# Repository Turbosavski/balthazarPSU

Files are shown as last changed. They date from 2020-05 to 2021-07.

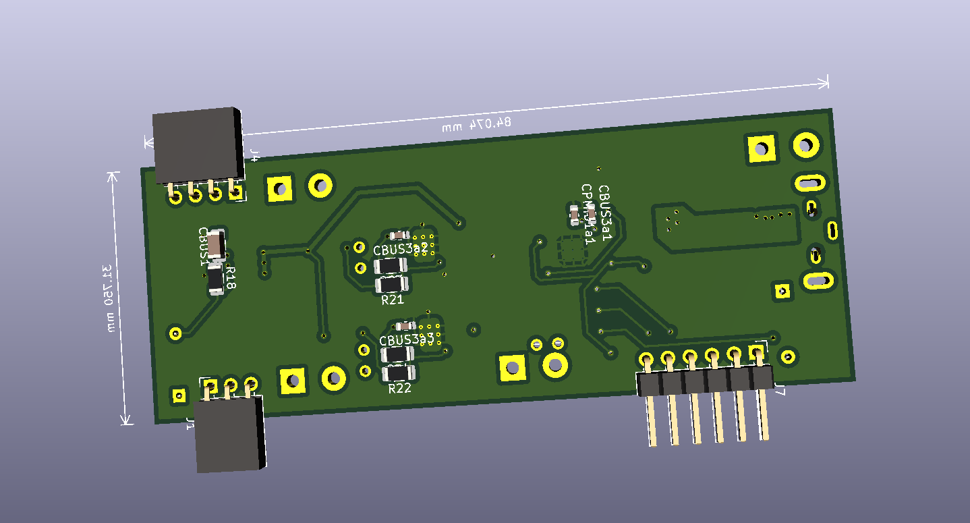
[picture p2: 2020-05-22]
BathazarPSU_11.png

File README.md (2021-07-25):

# balthazar
open-hardware laptop computer modules

These are electronic schematic modules as presented at https://balthazar.space/wiki/Balthazar
with the main aim for team access

KiCad 5.1.5 files

# BalthazarPSU 

module BalthazarPSU is a combined 1S battery charger, double buck-boost converter, stereo power amplifier and usb2.0 hub.

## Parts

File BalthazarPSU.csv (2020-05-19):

Reference | Value | Footprint | Datasheet
L1 | 2.2uH 4A | Inductor_SMD:L_Coilcraft_XxL4020
R7 | 265 | Resistor_SMD:R_1206_3216Metric
R4 | 2K2 | Resistor_SMD:R_1206_3216Metric
R5 | 2K2 | Resistor_SMD:R_1206_3216Metric
D1 | Led | LED_SMD:LED_1206_3216Metric
D2 | Led | LED_SMD:LED_1206_3216Metric
R3 | 10K | Resistor_SMD:R_1206_3216Metric
R2 | 10K | Resistor_SMD:R_1206_3216Metric
R1 | 10K | Resistor_SMD:R_1206_3216Metric
CPMID1 | 10uF | Capacitor_SMD:C_1206_3216Metric
CBUS3 | 1uF | Capacitor_SMD:C_1206_3216Metric
CSYS1 | 10uF | Capacitor_SMD:C_1206_3216Metric
CSYS2 | 10uF | Capacitor_SMD:C_1206_3216Metric
CREGN1 | 1uF | Capacitor_SMD:C_1206_3216Metric
RBTST1 | R | Resistor_SMD:R_1206_3216Metric
CBTST1 | 1uF | Capacitor_SMD:C_1206_3216Metric
R8 | 2K2 | Resistor_SMD:R_1206_3216Metric
R10 | 6K8 | Resistor_SMD:R_1206_3216Metric
THERMISTOR(103-AT)1 | 10K | Resistor_SMD:R_1206_3216Metric
R6 | 10K | Resistor_SMD:R_1206_3216Metric
U1 | PAM8403-SOP16 | Package_SO:SOP-16_4.4x10.4mm_P1.27mm | https://www.diodes.com/assets/Datasheets/PAM8403.pdf
CBUS5 | 1uF | Capacitor_SMD:C_1206_3216Metric
CBUS8 | 1uF | Capacitor_SMD:C_1206_3216Metric
R11 | 2K2 | Resistor_SMD:R_1206_3216Metric
R9 | 2K2 | Resistor_SMD:R_1206_3216Metric
CBUS7 | 0.1uF | Capacitor_SMD:C_1206_3216Metric
CBUS1 | 1uF | Capacitor_SMD:C_1206_3216Metric
CBUS2 | 1uF | Capacitor_SMD:C_1206_3216Metric
CBUS4 | 1uF | Capacitor_SMD:C_1206_3216Metric
D3 | RBR5LAM40A | Diode_SMD:D_SOD-128 | ~
CBAT1 | 10uF | Capacitor_SMD:C_1206_3216Metric
FBEAD3 | 10E | Inductor_SMD:L_Neosid_MicroCoil_Ms36-L
U2 | TPS63020 | Package_SON:WSON-14-1EP_4.0x4.0mm_P0.5mm_EP2.6x2.6mmThermalPads | http://www.ti.com/lit/ds/symlink/tps63060.pdf
U3 | TPS63020 | Package_SON:WSON-14-1EP_4.0x4.0mm_P0.5mm_EP2.6x2.6mmThermalPads | http://www.ti.com/lit/ds/symlink/tps63060.pdf
L2 | 1.5uH 4A | Inductor_SMD:L_Coilcraft_XxL4020
L3 | 1.5uH 4A | Inductor_SMD:L_Coilcraft_XxL4020
C1 | 0.1uF | Capacitor_SMD:C_1206_3216Metric
C2 | 0.1uF | Capacitor_SMD:C_1206_3216Metric
R12 | 1M | Resistor_SMD:R_1206_3216Metric
R14 | 1M | Resistor_SMD:R_1206_3216Metric
R13 | 180K | Resistor_SMD:R_1206_3216Metric
R15 | 180K | Resistor_SMD:R_1206_3216Metric
C3 | 22uF | Capacitor_SMD:C_1206_3216Metric
C5 | 22uF | Capacitor_SMD:C_1206_3216Metric
C7 | 22uF | Capacitor_SMD:C_1206_3216Metric
C9 | 22uF | Capacitor_SMD:C_1206_3216Metric
C4 | 22uF | Capacitor_SMD:C_1206_3216Metric
C6 | 22uF | Capacitor_SMD:C_1206_3216Metric
C8 | 22uF | Capacitor_SMD:C_1206_3216Metric
C10 | 22uF | Capacitor_SMD:C_1206_3216Metric
CSYS4 | 10uF | Capacitor_SMD:C_1206_3216Metric
SW2 | SW_SPST | Button_Switch_THT:SW_DIP_SPSTx01_Slide_6.7x4.1mm_W7.62mm_P2.54mm_LowProfile | ~
R16 | 10K | Resistor_SMD:R_1206_3216Metric
J5 | USB_A_female | Connector_USB:USB_A_CNCTech_1001-011-01101_Horizontal-Female | ~
J6 | USB_OTG_female | Connector_USB:USB_Micro-B_Molex-105133-0031 | ~
D6 | RBR5LAM40A | Diode_SMD:D_SOD-128 | ~
CPSU2 | 1uF | Capacitor_SMD:C_1206_3216Metric
R17 | 10K | Resistor_SMD:R_1206_3216Metric
SW3 | SW_SPST | Button_Switch_THT:SW_DIP_SPSTx01_Slide_6.7x4.1mm_W7.62mm_P2.54mm_LowProfile | ~
R18 | 10K | Resistor_SMD:R_1206_3216Metric
FBEAD2 | 10E | Inductor_SMD:L_Neosid_MicroCoil_Ms36-L
PSU1 | 3.9 - 17V adapter 3-5A | TerminalBlock:TerminalBlock_bornier-2_P5.08mm | ~
IC1 | BQ24193 | Package_DFN_QFN:QFN-24-1EP_4x4mm_P0.5mm_EP2.7x2.7mm_ThermalVias
J8 | 3.3V 4A | TerminalBlock:TerminalBlock_bornier-2_P5.08mm | ~
J4 | AudioOUT | Connector_PinSocket_2.54mm:PinSocket_1x04_P2.54mm_Horizontal | ~
J1 | AudioIN | Connector_PinSocket_2.54mm:PinSocket_1x03_P2.54mm_Horizontal | ~
R19 | 0 | Resistor_SMD:R_1206_3216Metric
R20 | 0 | Resistor_SMD:R_1206_3216Metric
J7 | host (promicro) | Connector_PinHeader_2.54mm:PinHeader_1x06_P2.54mm_Horizontal | ~
THERM1 | thermistor | TestPoint:TestPoint_2Pads_Pitch2.54mm_Drill0.8mm | ~
R23 | 1M | Resistor_SMD:R_1206_3216Metric
R24 | 1M | Resistor_SMD:R_1206_3216Metric
R22 | 2K2 | Resistor_SMD:R_1206_3216Metric
D5 | Led | LED_SMD:LED_1206_3216Metric
R21 | 2K2 | Resistor_SMD:R_1206_3216Metric
D4 | Led | LED_SMD:LED_1206_3216Metric
CSYS3 | 10uF | Capacitor_SMD:C_1206_3216Metric
R26 | 270K | Resistor_SMD:R_1206_3216Metric
J11 | 3.3V/5V | TestPoint:TestPoint_2Pads_Pitch2.54mm_Drill0.8mm | ~
J10 | 3.3V/5V | TestPoint:TestPoint_2Pads_Pitch2.54mm_Drill0.8mm | ~
R25 | 270K | Resistor_SMD:R_1206_3216Metric
CPSU1 | 1uF | Capacitor_SMD:C_1206_3216Metric
BATT1 | 1s LiPo | TerminalBlock:TerminalBlock_bornier-2_P5.08mm | ~
CBUS3a1 | 0.1uF | Capacitor_SMD:C_0805_2012Metric
CPMID1a1 | 0.1uF | Capacitor_SMD:C_0805_2012Metric
CBUS3a3 | 0.1uF | Capacitor_SMD:C_0805_2012Metric
CBUS3a2 | 0.1uF | Capacitor_SMD:C_0805_2012Metric
J9 | 3.3V 4A | TerminalBlock:TerminalBlock_bornier-2_P5.08mm | ~

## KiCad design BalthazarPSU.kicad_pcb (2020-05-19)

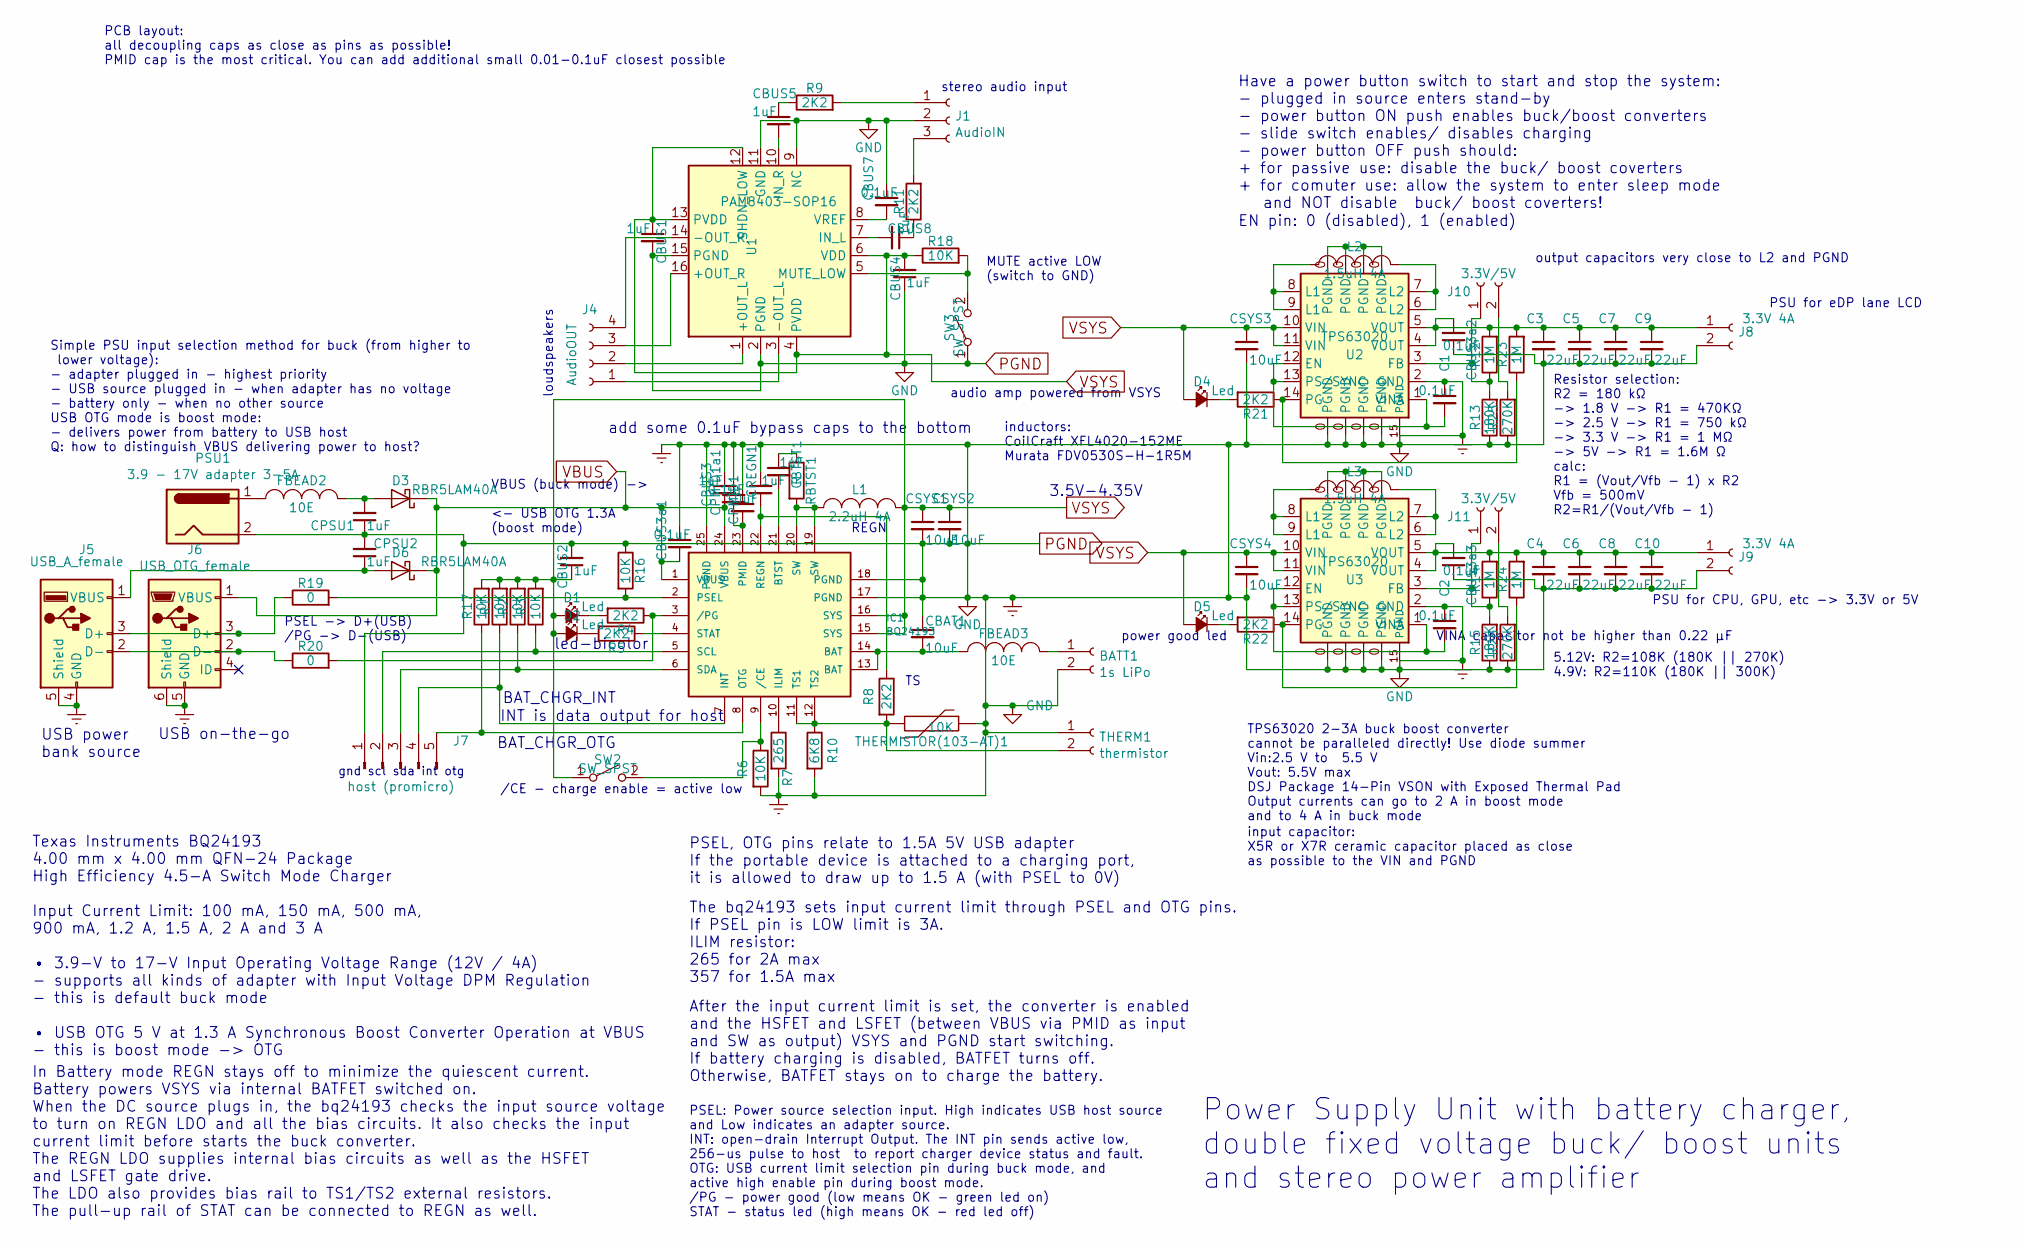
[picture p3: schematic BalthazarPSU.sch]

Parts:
BATT1: 1s LiPo; TerminalBlock_bornier-2_P5.08mm
C1, C2: 0.1uF; C_1206_3216Metric
C3, C4, C5, C6, C7, C8, C9, C10: 22uF; C_1206_3216Metric
CBAT1: 10uF; C_1206_3216Metric
CBTST1: 1uF; C_1206_3216Metric
CBUS1, CBUS2, CBUS3, CBUS4, CBUS5, CBUS8: 1uF; C_1206_3216Metric
CBUS3a1, CBUS3a2, CBUS3a3: 0.1uF; C_0805_2012Metric
CBUS7: 0.1uF; C_1206_3216Metric
CPMID1: 10uF; C_1206_3216Metric
CPMID1a1: 0.1uF; C_0805_2012Metric
CPSU1, CPSU2: 1uF; C_1206_3216Metric
CREGN1: 1uF; C_1206_3216Metric
CSYS1, CSYS2, CSYS3, CSYS4: 10uF; C_1206_3216Metric
D1, D2, D4, D5: Led; LED_1206_3216Metric
D3, D6: RBR5LAM40A; D_SOD-128
FBEAD2, FBEAD3: 10E; L_Neosid_MicroCoil_Ms36-L
IC1: BQ24193; QFN-24-1EP_4x4mm_P0.5mm_EP2.7x2.7mm_ThermalVias
J1: AudioIN; PinSocket_1x03_P2.54mm_Horizontal
J4: AudioOUT; PinSocket_1x04_P2.54mm_Horizontal
J5: USB_A_female; USB_A_CNCTech_1001-011-01101_Horizontal-Female
J6: USB_OTG_female; USB_Micro-B_Molex-105133-0031
J7: host (promicro); PinHeader_1x06_P2.54mm_Horizontal
J8, J9: 3.3V 4A; TerminalBlock_bornier-2_P5.08mm
J10, J11: 3.3V/5V; TestPoint_2Pads_Pitch2.54mm_Drill0.8mm
L1: 2.2uH 4A; L_Coilcraft_XxL4020
L2, L3: 1.5uH 4A; L_Coilcraft_XxL4020
PSU1: 3.9 - 17V adapter 3-5A; TerminalBlock_bornier-2_P5.08mm
R1, R2, R3, R6, R16, R17, R18: 10K; R_1206_3216Metric
R4, R5, R8, R9, R11, R21, R22: 2K2; R_1206_3216Metric
R7: 265; R_1206_3216Metric
R10: 6K8; R_1206_3216Metric
R12, R14, R23, R24: 1M; R_1206_3216Metric
R13, R15: 180K; R_1206_3216Metric
R19, R20: 0; R_1206_3216Metric
R25, R26: 270K; R_1206_3216Metric
RBTST1: R; R_1206_3216Metric
SW2, SW3: SW_SPST; SW_DIP_SPSTx01_Slide_6.7x4.1mm_W7.62mm_P2.54mm_LowProfile
THERM1: thermistor; TestPoint_2Pads_Pitch2.54mm_Drill0.8mm
THERMISTOR(103-AT)1: 10K; R_1206_3216Metric
U1: PAM8403-SOP16; SOP-16_4.4x10.4mm_P1.27mm
U2, U3: TPS63020; WSON-14-1EP_4.0x4.0mm_P0.5mm_EP2.6x2.6mmThermalPads

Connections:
unnamed: BATT1.1, FBEAD3.2
unnamed: C1.2, U2.1 (VINA), U2.12 (EN), U2.13 (PS/SYNC)
unnamed: C2.2, U3.1 (VINA), U3.12 (EN), U3.13 (PS/SYNC)
unnamed: C3.1, C5.1, C7.1, C9.1, CBUS3a2.2, J8.1, R12.2, R23.2, U2.4 (VOUT), U2.5 (VOUT)
unnamed: C4.1, C6.1, C8.1, C10.1, CBUS3a3.2, J9.1, R14.2, R24.2, U3.4 (VOUT), U3.5 (VOUT)
unnamed: CBAT1.2, FBEAD3.1, IC1.13 (BAT), IC1.14 (BAT)
unnamed: CBTST1.1, RBTST1.1
unnamed: CBTST1.2, IC1.21 (BTST)
unnamed: CBUS5.1, R9.1
unnamed: CBUS5.2, U1.10 (IN_R)
unnamed: CBUS7.2, U1.8 (VREF)
unnamed: CBUS8.1, R11.1
unnamed: CBUS8.2, U1.7 (IN_L)
unnamed: CPMID1.2, CPMID1a1.2, IC1.23 (PMID)
unnamed: CPSU1.2, D3.2 (A), FBEAD2.2
unnamed: CPSU2.1, D6.2 (A), J5.1 (VBUS)
unnamed: CREGN1.2, IC1.22 (REGN), R8.1
unnamed: D1.2 (C), R4.2
unnamed: D2.2 (C), R5.2
unnamed: D4.2 (C), R21.2
unnamed: D5.2 (C), R22.2
unnamed: FBEAD2.1, PSU1.1
unnamed: IC1.2 (PSEL), R16.2, R19.2
unnamed: IC1.3 (/PG), R4.1, R20.2
unnamed: IC1.4 (STAT), R5.1
unnamed: IC1.5 (SCL), J7.2, R3.1
unnamed: IC1.6 (SDA), J7.3, R2.1
unnamed: IC1.7 (INT), J7.4, R1.1
unnamed: IC1.8 (OTG), J7.5, R17.1
unnamed: IC1.9 (/CE), R6.1, SW2.2 (B)
unnamed: IC1.10 (ILIM), R7.1
unnamed: IC1.11 (TS1), IC1.12 (TS2), R8.2, R10.1, THERM1.2, THERMISTOR(103-AT)1.2
unnamed: IC1.19 (SW), IC1.20 (SW), L1.1, RBTST1.2
unnamed: J1.1, R9.2
unnamed: J1.3, R11.2
unnamed: J4.1, U1.3 (-OUT_L)
unnamed: J4.2, U1.1 (+OUT_L)
unnamed: J4.3, U1.16 (+OUT_R)
unnamed: J4.4, U1.14 (-OUT_R)
unnamed: J5.2 (D-), J6.2 (D-), R20.1
unnamed: J5.3 (D+), J6.3 (D+), R19.1
unnamed: J10.1, R12.1, R13.2, U2.3 (FB)
unnamed: J10.2, R25.2
unnamed: J11.1, R14.1, R15.2, U3.3 (FB)
unnamed: J11.2, R26.2
unnamed: L2.1, U2.8 (L1), U2.9 (L1)
unnamed: L2.2, U2.6 (L2), U2.7 (L2)
unnamed: L3.1, U3.8 (L1), U3.9 (L1)
unnamed: L3.2, U3.6 (L2), U3.7 (L2)
unnamed: R18.2, SW3.2 (B), U1.5 (MUTE_LOW)
unnamed: R21.1, R23.1, U2.14 (PG)
unnamed: R22.1, R24.1, U3.14 (PG)
VBUS: CBUS3.2, CBUS3a1.2, D3.1 (K), D6.1 (K), IC1.1 (VBUS), IC1.24 (VBUS), J6.1 (VBUS)
VSYS: CBUS1.1, CBUS2.1, CBUS4.2, CSYS1.1, CSYS2.1, CSYS3.1, CSYS4.1, D1.1 (A), D2.1 (A), D4.1 (A), D5.1 (A), IC1.15 (SYS), IC1.16 (SYS), L1.2, R1.2, R2.2, R3.2, R17.2, R18.1, SW2.1 (A), U1.4 (PVDD), U1.6 (VDD), U1.12 (SHDN_LOW), U1.13 (PVDD), U2.10 (VIN), U2.11 (VIN), U3.10 (VIN), U3.11 (VIN)

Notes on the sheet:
3.5V-4.35V
USB on-the-go
led-bicolor
BAT_CHGR_INT
BAT_CHGR_OTG
INT is data output for host
Texas Instruments BQ24193 4.00 mm x 4.00 mm QFN-24 Package High Efficiency 4.5-A Switch Mode Charger Input Current Limit: 100 mA, 150 mA, 500 mA, 900 mA, 1.2 A, 1.5 A, 2 A and 3 A • 3.9-V to 17-V Input Operating Voltage Range (12V / 4A) - supports all kinds of adapter with Input Voltage DPM Regulat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
PSEL, OTG pins relate to 1.5A 5V USB adapter If the portable device is attached to a charging port, it is allowed to draw up to 1.5 A (with PSEL to 0V)
In Battery mode REGN stays off to minimize the quiescent current. Battery powers VSYS via internal BATFET switched on. When the DC source plugs in, the bq24193 checks the input source voltage to turn on REGN LDO and all the bias circuits. It also checks the input current limit before starts the buc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
The bq24193 sets input current limit through PSEL and OTG pins. If PSEL pin is LOW limit is 3A. ILIM resistor: 265 for 2A max 357 for 1.5A max
After the input current limit is set, the converter is enabled and the HSFET and LSFET (between VBUS via PMID as input and SW as output) VSYS and PGND start switching. If battery charging is disabled, BATFET turns off. Otherwise, BATFET stays on to charge the battery.
PSU for CPU, GPU, etc -> 3.3V or 5V
TPS63020 2-3A buck boost converter cannot be paralleled directly! Use diode summer Vin:2.5 V to 5.5 V Vout: 5.5V max DSJ Package 14-Pin VSON with Exposed Thermal Pad Output currents can go to 2 A in boost mode and to 4 A in buck mode
inductors: CoilCraft XFL4020-152ME Murata FDV0530S-H-1R5M
Resistor selection: R2 = 180 kΩ -> 1.8 V -> R1 = 470KΩ -> 2.5 V -> R1 = 750 kΩ -> 3.3 V -> R1 = 1 MΩ -> 5V -> R1 = 1.6M Ω calc: R1 = (Vout/Vfb - 1) x R2 Vfb = 500mV R2=R1/(Vout/Vfb - 1)
REGN
stereo audio input
loudspeakers
MUTE active LOW (switch to GND)
/CE - charge enable = active low
PSEL: Power source selection input. High indicates USB host source and Low indicates an adapter source. INT: open-drain Interrupt Output. The INT pin sends active low, 256-us pulse to host to report charger device status and fault. OTG: USB current limit selection pin during buck mode, and active h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
PSEL -> D+(USB) /PG -> D-(USB)
Power Supply Unit with battery charger, double fixed voltage buck/ boost units and stereo power amplifier
PCB layout: all decoupling caps as close as pins as possible! PMID cap is the most critical. You can add additional small 0.01-0.1uF closest possible
PSU for eDP lane LCD
audio amp powered from VSYS
VBUS (buck mode) -> <- USB OTG 1.3A (boost mode)
Simple PSU input selection method for buck (from higher to lower voltage): - adapter plugged in - highest priority - USB source plugged in - when adapter has no voltage - battery only - when no other source USB OTG mode is boost mode: - delivers power from battery to USB host Q: how to distinguish 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
output capacitors very close to L2 and PGND
input capacitor: X5R or X7R ceramic capacitor placed as close as possible to the VIN and PGND
VINA capacitor not be higher than 0.22 μF
power good led
5.12V: R2=108K (180K || 270K) 4.9V: R2=110K (180K || 300K)
USB power bank source
gnd scl sda int otg
add some 0.1uF bypass caps to the bottom
EN pin: 0 (disabled), 1 (enabled)
Have a power button switch to start and stop the system: - plugged in source enters stand-by - power button ON push enables buck/boost converters - slide switch enables/ disables charging - power button OFF push should: + for passive use: disable the buck/ boost coverters + for comuter use: allow t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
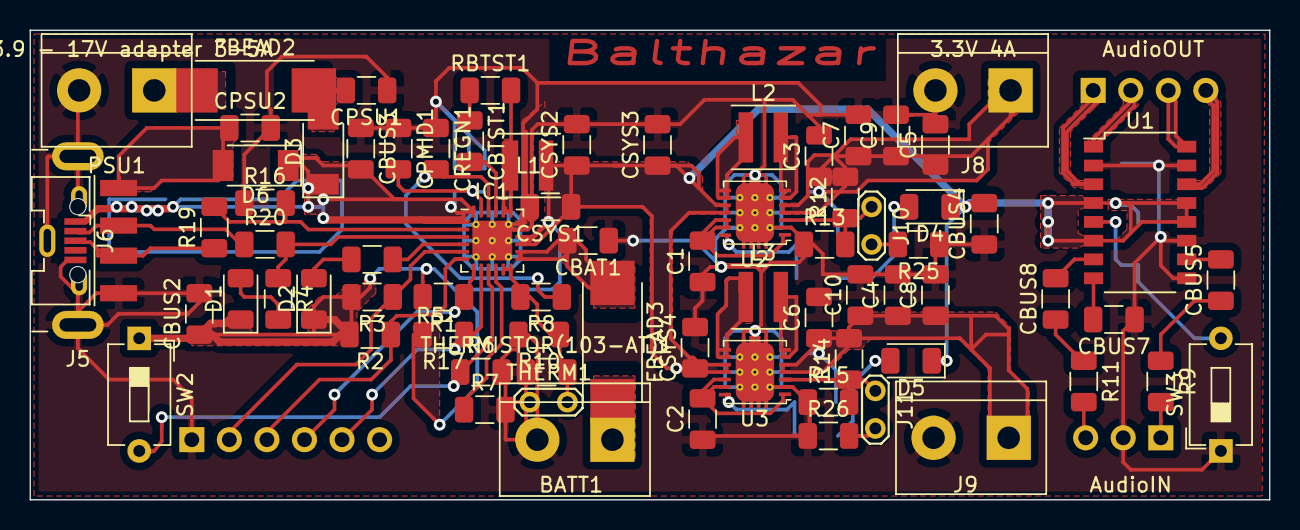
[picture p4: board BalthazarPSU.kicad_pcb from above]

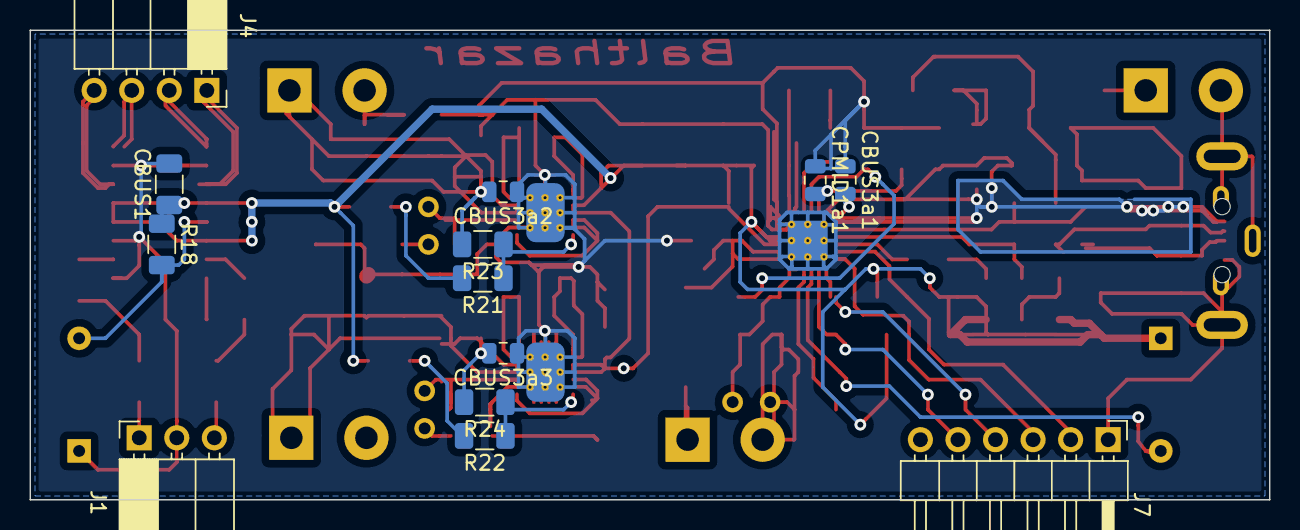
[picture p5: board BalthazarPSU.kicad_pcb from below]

Board: 2 copper layers, 83.8 x 31.8 mm, 88 parts (13 on the bottom side), 55 nets.
